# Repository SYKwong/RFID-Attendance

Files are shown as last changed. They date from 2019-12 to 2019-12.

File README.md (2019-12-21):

# [RFID Attendance](https://sites.google.com/view/rfid-project/home)

# Set up

## Arduino
- Follow [Sparkfun's guide](https://learn.sparkfun.com/tutorials/simultaneous-rfid-tag-reader-hookup-guide/introduction) to apply thermal pad, and attach the external antenna
    
- Follow [Sparkfun's instruction](https://learn.sparkfun.com/tutorials/simultaneous-rfid-tag-reader-hookup-guide/using-the-arduino-library) to install the Arduino library

- The code is a modified version of the example 2 from the [SparkFun Simultaneous RFID Tag Reader Library](https://github.com/sparkfun/SparkFun_Simultaneous_RFID_Tag_Reader_Library/tree/master/examples)

## Raspberry Pi
- We used Raspbian, but any Linux distro that is fully compatible with Raspberry Pi should work
- Download and follow the instruction for [NOOBS/Raspbian](https://www.raspberrypi.org/downloads/), or other fully compatible Linux distros of your choice(Pathing needs to be changed accordingly)
- Install the required modules using
    ```
    pip3 install gspread
    pip3 install oauth2client
    pip3 install python-crontab
    ```
- GPIO_18 is being used to turn on/off the RFID reader
    - RFID reader is on when the program is executing, and off after the Raspberry Pi finishs executing the program

## Google Sheet
- Follow the steps to get the [credentials for the Google sheet](https://gspread.readthedocs.io/en/latest/oauth2.html)
- Change the credential file name to `creds.json`
- Put it in the `ATTENDANCE` folder

## Running
**Arduino**
- Download `RFID.ino`, and upload it to the Arduino

**Raspberry Pi**
- Download the `ATTENDANCE` folder and place it on the Desktop `/home/pi/Desktop`
- Make sure the following files are in `/home/pi/Desktop/ATTENDANCE/`
    ```
    creds.json
    handler.py
    scheduler.py
    ```
- Make sure the schedule is in the first sheet of the spreadsheet and in the format of
    ```
    Column 1    Column 2    Column 3    Column 4
    Class-Name  Class-Time  Meeting-Day Section
    ```
    - *First row* is unchecked as it is only used for reference purposes
    - *Class-Time* needs to be in 24-hour format HH:MM
    - *Meeting-Day* uses NMTWRFS for
    ```
    suNday
    Monday
    Tuesday
    Wednesday
    thuRsday
    Friday
    Saturday
    ```
    - *Section* refers to the nth+1 sheet of the spreadsheet
- Open the terminal and run the schudler using 
    ```
    python3 ~/Desktop/ATTENDANCE/scheduler.py
    ```

## Case
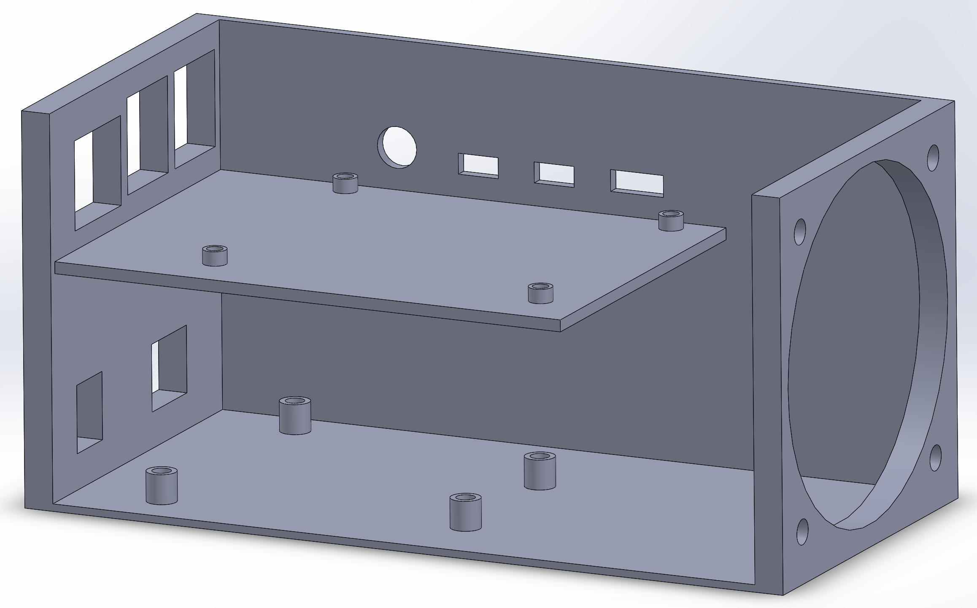
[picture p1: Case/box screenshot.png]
Box

Arduino and Reader sits at the bottom and the Pi sits above. The larger hole is where the fan is mounted inside the structure and blows in. The dimensions are 65.75mm wide, 71.25mm tall, and 127mm long. 

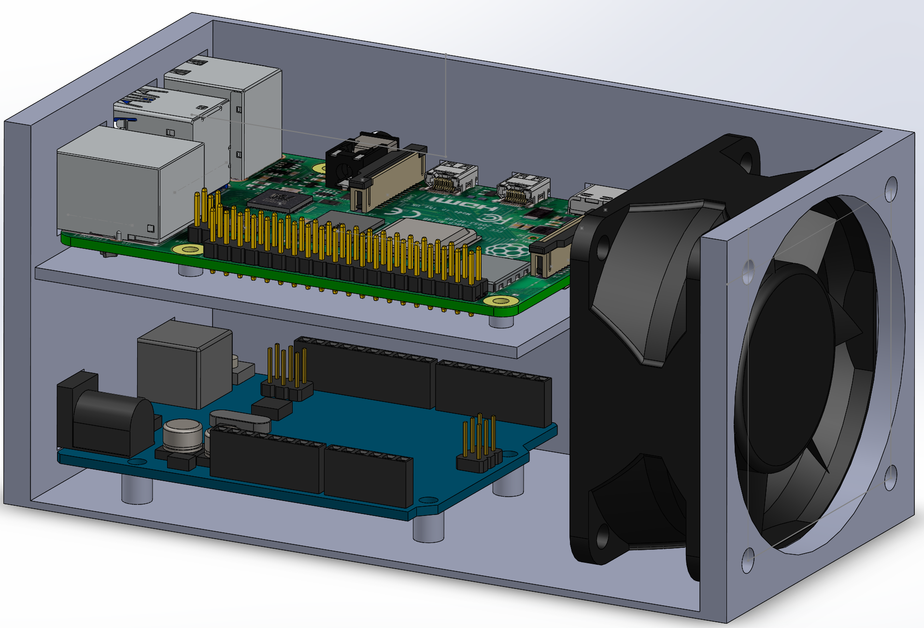
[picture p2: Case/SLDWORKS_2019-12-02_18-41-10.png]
BoxWithStuff

- An example of how all the pieces would fit together inside. The Solidworks models and files for the devices were borrowed from online sources. This does not include the RFID Tag Reader shield attached to the Arduino, however we took many measurements to ensure that there would be enough room for the reader the jumper cables coming out of the shield. 
Files containing the CAD designs of the Raspberry Pi 4, the Arduino UNO R3, and the 60mm fan: 
    - [Raspberry Pi 4](https://grabcad.com/library/raspberry-pi-4-model-b-1) 
    - [Arduino](https://my.solidworks.com/asset/3f1ffe37-e6ff-4405-ba55-ce50e84128bf)
    - [60mm fan](https://grabcad.com/library/cooling-fan-60x60x25-1)

## Known Issue
- Powering the Arduino via USB
    We were able to fully power the Arduino with the RFID reader and external antenna on; however, it would brownout(?) on some device, but having an external 9V power supply seemed to have solved the problem.

- `scheduler.py` has a bug where if Class-Time is 00:00, the cron table would produce an error, but since it is unrealistic to have a class at 00:00, we decided to ignore it.

- Hardware limitation on the UHF RFID reader
    If one tag has a dominate electromagnetic field, the reader would only be able to detect that tag.

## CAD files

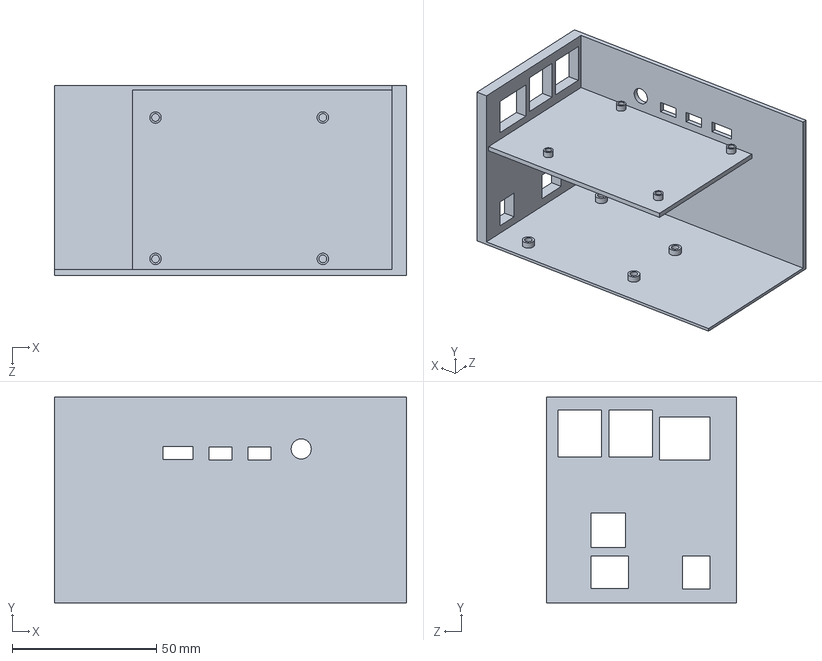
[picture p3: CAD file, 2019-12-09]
Case/box.SLDPRT
122.0 x 71.2 x 65.8 mm

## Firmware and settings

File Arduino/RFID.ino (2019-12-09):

/*
  Reading multiple RFID tags, simultaneously!
  By: Nathan Seidle @ SparkFun Electronics
  Date: October 3rd, 2016
  https://github.com/sparkfun/Simultaneous_RFID_Tag_Reader

  Single shot read - Ask the reader to tell us what tags it currently sees. And it beeps!

  If using the Simultaneous RFID Tag Reader (SRTR) shield, make sure the serial slide
  switch is in the 'SW-UART' position.
*/

#include <SoftwareSerial.h> //Used for transmitting to the device

SoftwareSerial softSerial(2, 3); //RX, TX

#include "SparkFun_UHF_RFID_Reader.h" //Library for controlling the M6E Nano module
RFID nano; //Create instance

#define BUZZER1 9
//#define BUZZER1 0 //For testing quietly
#define BUZZER2 10

void setup()
{
  Serial.begin(115200);

  pinMode(BUZZER1, OUTPUT);
  pinMode(BUZZER2, OUTPUT);

  digitalWrite(BUZZER2, LOW); //Pull half the buzzer to ground and drive the other half.

  while (!Serial);
  Serial.println();
  Serial.println("Initializing...");

  if (setupNano(38400) == false) //Configure nano to run at 38400bps
  {
    Serial.println("Module failed to respond. Please check wiring.");
    while (1); //Freeze!
  }

  nano.setRegion(REGION_NORTHAMERICA); //Set to North America

  nano.setReadPower(2000); //5.00 dBm. Higher values may cause USB port to brown out
  //Max Read TX Power is 27.00 dBm and may cause temperature-limit throttling
}

void loop()
{

  byte myEPC[12]; //Most EPCs are 12 bytes
  byte myEPClength;
  byte responseType = 0;

  while (responseType != RESPONSE_SUCCESS)//RESPONSE_IS_TAGFOUND)
  {
    myEPClength = sizeof(myEPC); //Length of EPC is modified each time .readTagEPC is called

//    tone(BUZZER1, 1975, 50); //B
//    delay(500);

    responseType = nano.readTagEPC(myEPC, myEPClength, 1000); //Scan for a new tag up to 750ms
//    Serial.println(F("Searching for tag"));

//    tone(BUZZER1, 988, 50); //B???
//    delay(500);
  }

  //Beep! Piano keys to frequencies: http://www.sengpielaudio.com/KeyboardAndFrequencies.gif
  //  tone(BUZZER1, 2093, 300); //C
  //  delay(300);
  //  tone(BUZZER1, 2349, 150); //D
  //  delay(150);
  tone(BUZZER1, 988, 150); //B??
  delay(150);



  //Print EPC
//  Serial.print(F(" epc["));
  for (byte x = 0 ; x < myEPClength ; x++)
  {
    if (myEPC[x] < 0x10) Serial.print(F("0"));
    Serial.print(myEPC[x], HEX);
//    Serial.print(F(" "));
  }
  Serial.println();

}



//void loop(){
//  nano.getReadPower();
//  Serial.print("\n");
//  
//  tone(BUZZER1, 1975, 500); //B
//  delay(1000);
//  
//}
//Gracefully handles a reader that is already configured and already reading continuously
//Because Stream does not have a .begin() we have to do this outside the library
boolean setupNano(long baudRate)
{
  nano.begin(softSerial); //Tell the library to communicate over software serial port

  //Test to see if we are already connected to a module
  //This would be the case if the Arduino has been reprogrammed and the module has stayed powered
  softSerial.begin(baudRate); //For this test, assume module is already at our desired baud rate
  while (!softSerial); //Wait for port to open

  //About 200ms from power on the module will send its firmware version at 115200. We need to ignore this.
  while (softSerial.available()) softSerial.read();

  nano.getVersion();

  if (nano.msg[0] == ERROR_WRONG_OPCODE_RESPONSE)
  {
    //This happens if the baud rate is correct but the module is doing a ccontinuous read
    nano.stopReading();

    Serial.println(F("Module continuously reading. Asking it to stop..."));

    delay(1500);
  }
  else
  {
    //The module did not respond so assume it's just been powered on and communicating at 115200bps
    softSerial.begin(115200); //Start software serial at 115200

    nano.setBaud(baudRate); //Tell the module to go to the chosen baud rate. Ignore the response msg

    softSerial.begin(baudRate); //Start the software serial port, this time at user's chosen baud rate
  }

  //Test the connection
  nano.getVersion();
  if (nano.msg[0] != ALL_GOOD) return (false); //Something is not right

  //The M6E has these settings no matter what
  nano.setTagProtocol(); //Set protocol to GEN2

  nano.setAntennaPort(); //Set TX/RX antenna ports to 1

  return (true); //We are ready to rock
}

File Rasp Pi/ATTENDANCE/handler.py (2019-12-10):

#!/bin/python3

import sys
import gspread
import datetime
from oauth2client.service_account import ServiceAccountCredentials
from pprint import pprint
import serial
import time
import RPi.GPIO as GPIO

#for logging purpose
print("start ", datetime.datetime.now())

GPIO.setmode(GPIO.BCM)
GPIO.setwarnings(False)
GPIO.setup(18, GPIO.OUT)

ser = serial.Serial('/dev/ttyACM0', 115200)
ser.close()
ser.open()

scope = ["https://spreadsheets.google.com/feeds",'https://www.googleapis.com/auth/spreadsheets',"https://www.googleapis.com/auth/drive.file","https://www.googleapis.com/auth/drive"]
creds = ServiceAccountCredentials.from_json_keyfile_name("/home/pi/Desktop/ATTENDANCE/creds.json", scope)
client = gspread.authorize(creds)

googleSheet = client.open("ATTENDANCE")

attendance = set()

time.sleep(5)
GPIO.output(18, 1)
time.sleep(5)

def rfid():
    fail = 0
    ser.close()
    ser.open()
    end = time.time() + 60*20
    while time.time() < end:
        line = ser.readline()
        linestr = str(line)
        linestr = linestr.strip(" 'b\\n\\r")
        if linestr == "Module failed to respond. Please check wiring.":
            # Reset the RFID reader if it outputs an error
             ser.close()
             ser.open()
             fail = 1
             if fail > 0:
                 GPIO.output(18, 0)
                 time.sleep(5)
                 GPIO.output(18, 1)
                 time.sleep(5)
        else:
            attendance.add(linestr)
            # Else just add the output to the attendance set

def update(classIndex):
    #Get the current date in MM/DD/YY
    date = datetime.datetime.today().strftime("%m/%d/%y")

    #Get the sheet
    classSheet = googleSheet.get_worksheet(classIndex)

    #Get the index for starting column
    offset = len(classSheet.row_values(1))+1

    #Add an extra column if the sheet is out of columns
    if offset>=26:
        classSheet.resize(None, offset)

    #Get the column with the students' EPC numbers
    enrollment = classSheet.col_values(2)
    #The first value from the column is "EPC number"
    enrollment.pop(0)

    #Update the value of the first cell from the starting column with the current date
    classSheet.update_cell(1,offset, date)

    #Check if student is present
    for student in attendance:
        if student in enrollment:
            studentIndex = enrollment.index(student)+2
            classSheet.update_cell(studentIndex, offset, "1")

if __name__ == '__main__':
    classIndex = int(sys.argv[1])

    rfid()
    GPIO.output(18, 0)

    update(classIndex)

    #for logging purpose
    print("end ", datetime.datetime.now())
